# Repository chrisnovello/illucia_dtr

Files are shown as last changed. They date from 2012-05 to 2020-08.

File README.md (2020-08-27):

illucia dtr
a patchbay controller 
by [Chris Novello](http://chrisnovello.com) ([@chrisnovello](http://www.twitter.com/chrisnovello))   

It uses physical jacks and patch cables as an interface for making connections between computer programs. 

It is open source everything: hardware, software (microcontroller & computer side), and design.

For more info, visit [illucia.com](http://www.illucia.com) and read the [FAQ](http://www.illucia.com/faq/) and [user guide](http://www.illucia.com/guide/).

## Microcontroller Installation

Teensy++ 2.0
Requires installation of [Teensy extension](https://www.pjrc.com/teensy/td_download.html) for Arduino IDE. Choose correct board model from Tools menu. Click verify, press button on board, upload code to board.

* On my computer, the serial device shows up as `/dev/cu.usbmodem1421`
* Baud setting is 9600.

## Pin mappings

Pins are mapped into arrays. The index of this array is the numeric ID followed by the type of the controller.

## Firmware design 

What is a handshake?

There's a boolean, true by default that instructs the program that it "needs a handshake". Why would it not need one?

What is a Device State?

There is a class called ControlElement that has two setters. Pin number and symbolic ID. This is the base class for all other element types.

A DigitalElement inherits ControlElement with some attributes for byte value, and debouncing data. There defaults for attributes are to say debounce is false and set the byte value to something outside of the expected range. There are getters and setters for the byte data, in this case all expected byte values are boolean. The main class has a single function with no return value named updateState() with no arguments. It gets the current pin number from the parent class.

It seems like the pull up resistors for all the LED and jack connections indicate that a state change will "flip the bit". For example, if the pin read is HIGH, send a 0. From here the function allocates a 4 byte array like 

```
  byte dataToSend[MESSAGE_SIZE] = {
      DIGITAL_TYPE, lowByte(_id), valueToSend, 255
  }
```
Note last byte is FF. This is padding.

A ContinuousElement inherits ControlElement and adds a single attribute for the previous read. It has a single function named updateState() that returns an int. Why is this pattern different than the updateState() function for DigitalElement?

There is some software filtering for noise then it packs the 4 byte array like so

```
  byte bytesToSend[MESSAGE_SIZE] = {
      CONTINUOUS_TYPE, _id, highByte(reading), lowByte(reading)
  };
```

Simple!

The Jack class inherits from ControlElement but also creates instances of DigitalElement, which is strange. It looks like there is some iterative stuff going on here, which makes sense, but we really have a 4x4 matrix with each point having a streaming input or output. 

What is Debouncing? 

Debouncing appears to be a short delay window to not read a value but rather reread the value after this delay. Why this might be some kind of error correction to smooth out the electrical interference which could effect the corectness of the values coming from the controllers.

What is "first byte pertaining to the state of the grid (for now, just beaming the whole state of the grid over when something changes)"?

The serial protocol has the following structure, though there is logic within the array. Perhaps this logic could be better represented through data modeling?

[
int controllerType,
int controllerID,
byte controllerValue,
]

For example, the controllerType changes the meaning of the controllerID. If the type is a jack connection, the controllerID "beams the whole state of the grid over". I'm not sure what that means but it seems like it's larger than simply identifying the jack identifier which has changed.

Also, the controllerType changes the meaning of the controllerValue. If the type is 0, the last two bytes are the value of the controller for this sample. If the type is 1, the controllerValue is a simple boolean (1bit). If the type is 2 the controllerValue is the controllerID of the other jack connection and a boolean to signify if the connection is open or closed.

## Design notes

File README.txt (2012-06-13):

illucia dtr is a codebending instrument. 

It uses physical jacks and patch cables as an interface for making connections between computer programs. 

It is open source everything: hardware, software (microcontroller & computer side), and design.

For more information, visit:
http://www.paperkettle.com
http://www.illucia.com

http://www.twitter.com/paperkettle

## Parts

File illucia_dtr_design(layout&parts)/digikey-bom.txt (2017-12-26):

Index,Quantity,Part Number,Description,Customer Reference,Available Quantity,Backorder Quantity,Unit Price USD,Extended Price USD,
1,5,360-1801-ND,SWITCH TOGGLE SPDT 6A 125V,,5,0,3.55000,17.75,
2,5,CKN4022-ND,SWITCH PUSH SPDT 0.4VA 20V,,5,0,5.21000,26.05,
3,5,CKN1399-ND,CAP PUSHBUTTON ROUND RED,,5,0,0.86000,4.30,
4,5,360-3215-ND,NUT CONICAL INCH FOR EB/MB20 SER,,5,0,1.04000,5.20,
5,5,CLB_300_RTP-ND,LENS MT CLIPLITE 5MM RED TRANSP,,5,0,0.63000,3.15,
6,7,450-1731-ND,SWITCH KNOB STRGHT 1.02" W/SKIRT,,7,0,2.92600,20.48,
7,2,A121571-ND,CONN USB RCPT VERT A TYPE WHITE,,2,0,1.09000,2.18,
8,1,MUSBB55104-ND,CONN RUGGED USB RCPT VERT MINI B,,1,0,13.92000,13.92,
,,,,,,Subtotal,93.03
,,,,,,Shipping,unknown
,,,,,,Estimated Sales Tax,7.91
,,,,,,Total,unknown

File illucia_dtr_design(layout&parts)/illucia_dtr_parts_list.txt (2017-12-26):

illucia parts list:

========================================

Enclosure (1) [acrylic, nb]
	Hammond 1590DD
        http://www.alliedelec.com/hammond-manufacturing-1590dd/70165498/

Banana Jack (16) [nb]
	Emerson/Johnson 108-09xx-001 

Toggle Switch (4) [https://www.digikey.com/product-detail/en/nkk-switches/M2012SS1W01/360-1801-ND/1006880]
	NKK M2012SS1W01 (alt: M2012ES1W01 has bat switches)

Momentary Pushbutton (4) [https://www.digikey.com/products/en?keywords=8125SHZBE]
	C&K 8125SHZBE 

Red Button Cap (4) [https://www.digikey.com/products/en?keywords=%20801803000]
	C&K 801803000 

Conical Dress Nut (4) [https://www.digikey.com/product-detail/en/nkk-switches/AT512H/360-3215-ND/1045995]
	NKK AT512H 

LED (4) [nb]
	Diffused Red

LED Lens (4) [https://www.digikey.com/products/en?keywords=593-3000R]
	593-3000R

ESD Resistors (16) [nb] 
	100 ohms

LED Resistors [nb]
	1k

Potentiometers (6) [https://www.mammothelectronics.com/collections/alpha-pcb-mount/products/alpha-16mm-single-gang-long-pin-right-angle-pc-mount-logarithmic-a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]
	RV16AF-42-15R1-A10k Linear Alpha Single-Gang 16mm Right Angle PC Mount Long-Pin

Knobs (6) [https://www.digikey.com/products/en?keywords=506-PKD70B1%2F4]
	506-PKD70B1/4

USB A Receptacle (1) [https://www.digikey.com/products/en?keywords=1734366-2]
	1734366-2
 
Amphenol Rugged Mini USB Receptacle (1) [https://www.digikey.com/products/en?keywords=MUSB-B551-04]
	MUSB-B551-04

Screws (2) [nb]
	M2.5 (I think… whatever fits amphenol's threads)

Teensy++ w/header pins (1) [https://www.pjrc.com/store/teensypp.html]
	
Female Headers20 pin .1" spacing female headers (2) [nb]

== Distributors ==

NKK Switches
http://www.nkkswitches.com/

C&K Switches
http://www.ckswitches.com/

Digikey Electronics
https://www.digikey.com

PJRC
https://www.pjrc.com//

== Digikey BOM ==

http://www.digikey.com/short/3dztqt

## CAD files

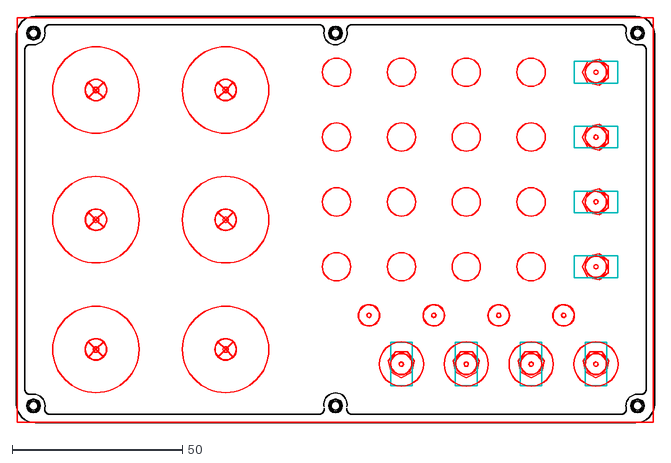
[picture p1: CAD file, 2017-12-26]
illucia_dtr_design(layout&parts)/vector/holes_mm.dxf
187.5 x 119.4

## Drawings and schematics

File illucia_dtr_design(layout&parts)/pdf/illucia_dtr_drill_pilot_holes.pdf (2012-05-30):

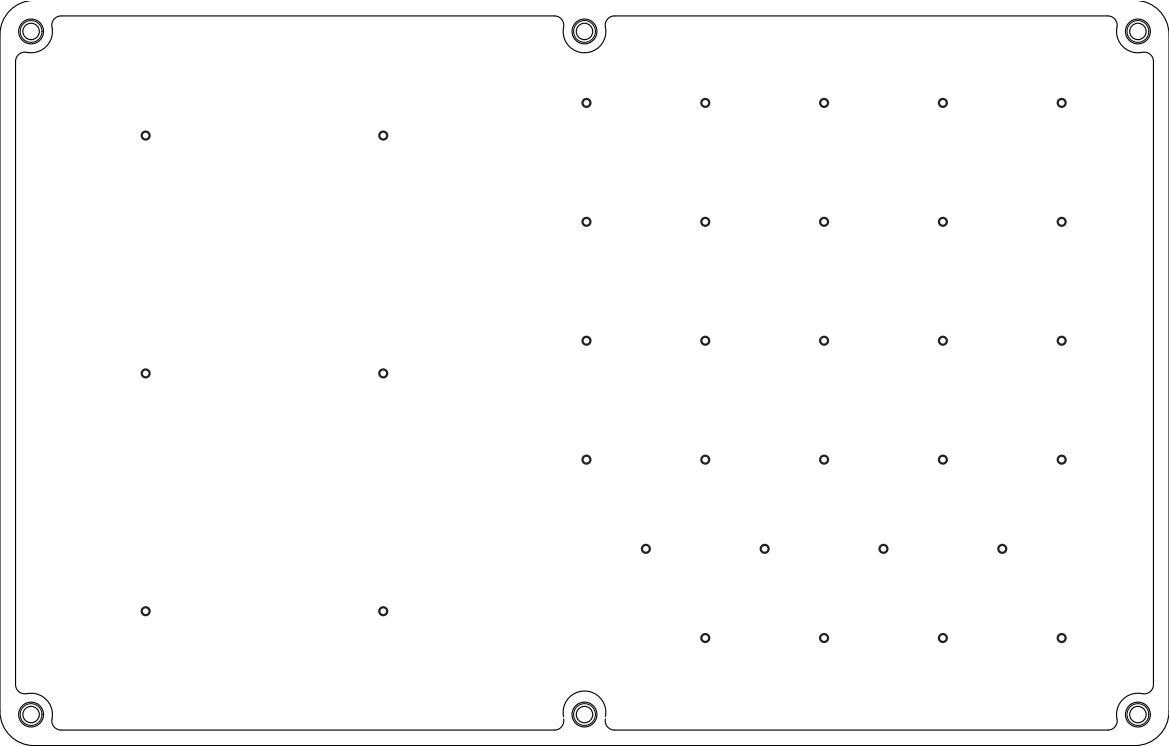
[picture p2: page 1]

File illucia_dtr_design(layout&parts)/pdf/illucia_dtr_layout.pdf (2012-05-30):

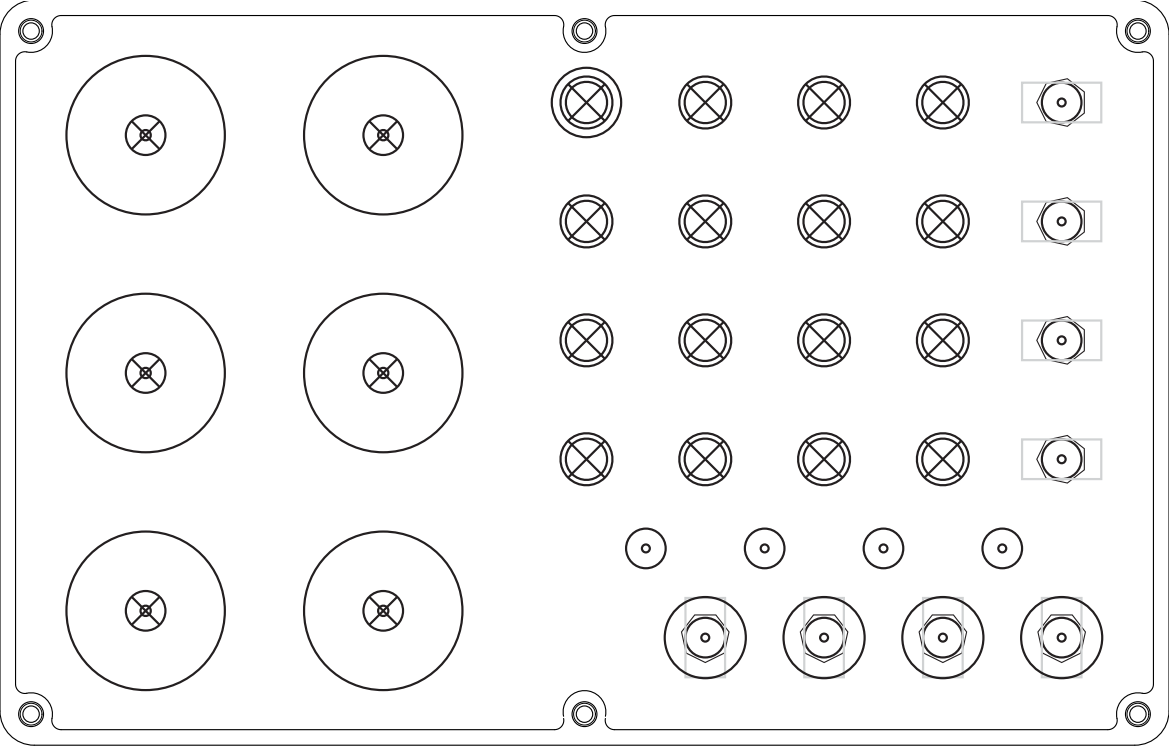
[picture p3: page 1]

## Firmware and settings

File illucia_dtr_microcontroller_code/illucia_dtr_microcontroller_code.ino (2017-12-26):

/*
 Todo:
 -After first correspondence handshake, broadcast information about device
 Computer will use this to dynamically create a model of the device
 */

/*
 illucia dtr
 "deterritorializer"
 microcontroller code version 0.9
 arduino style code (with Teensy++ as the intended target at the moment)
 
 When there is a change in state, send a message to the computer specifiying the change. 
 The message is a 4 byte array with the makeup:
 
 //first byte: char representaiton of type of control element that this message pertains to
 0 = continuous (potentiometer, sensor, etc)
 1 = digital (button, switch, etc)
 2 = jack event (some jack connection or disconnection)
 3 = arbitrary data (currently unused)
 
 //second byte
 if continous or digital: ID number of control element (ie: which pot changed, or which button changed)
 if jack events: first byte pertaining to the state of the grid (for now, just beaming the whole state of the grid over when something changes)
 if arbitrary data: first byte of whatever data is being sent
 
 //remaining bytes:
 if continuous: send 2 bytes (the 10bit value from the analogRead) 
 if digital: send 1 byte (only 1 bit used). send 1 for pressed, 0 for released 
 if jack event: another jack is involved, so send its ID in the next byte, and another byte pertaining to the state (0 for a disconnection, 1 for a connection)
 */

//Constants:
byte const CONTINUOUS_TYPE = 0;
byte const DIGITAL_TYPE = 1;
byte const JACK_TYPE = 2;

int const MESSAGE_SIZE = 4; //4 bytes transmitted every serial message

int const NUMBER_OF_DIGITAL_ELEMENTS = 8; // how many buttons & switches?
int const NUMBER_OF_CONTINUOUS_ELEMENTS = 6; // how many continuous controls?
int const NUMBER_OF_JACKS = 16; //how many jacks are on this device?

//debouncing&smoothing
int const DEBOUNCE_DELAY = 20;//how many MS should you wait for a debounced value?
int const ANALOG_CHANGE_THRESHOLD = 6; //used for software smoothing of analogRead jitter

//For incoming data to microcontroller:
byte const RESET_TYPE = 0; //used to tell the device to go back to waiting for a handshake
byte const LED_TYPE = 1; //used to specify an LED's brightness
int const NUMBER_OF_LEDS = 4; //how many LEDs are on this device?


//Pin Setup
//these are lists of the microcontroller pins used. the order that they're listed will determine the control element's ID (as in, what number button or switch or potentiometer etc)
int digitalElementPins[] = { //pins hooked up to "digital" elements like buttons / switches. 
    18, 19, 20, 21, 22, 23, 44 ,45
}; 
int continuousElementPins[] = { //analog I/O (aka pots.... FRESH POTS!!!!)
    0, 1, 2, 3, 4, 5
};
int jackPins[] = {
    0,1,2,3,4,5,7,8,9,10,11,12,13,14,15,16
    //  17, 16, 15, 13, 12, 11, 10, 9, 32, 33, 34, 35, 8, 7, 5, 4
};
int ledPins[] = {
    24, 25, 26, 27
};



boolean needsHandshake = true; //used to determine if communication has been initiated with the device or not

//Base class for keeping track of the device's state
class ControlElement {
public:
    
    int _pinNumber; //the microcontroller pin associated with this element
    int _id; //the number of this element (aka, is it jack1, jack2, knob1, knob2, etc)
    
    void setPinNumber(int pinNumber) {
        _pinNumber = pinNumber; 
    }
    
    void setId(int id) {
        _id = id; 
    }
    
};


//Used to keep state of switches, buttons, jack connections.. anything that is on/off, needs debouncing, and is checked with a digital pin on the microcontroller
class DigitalElement : public ControlElement {
public:
    
    byte _value;
    
    boolean _debouncing;
    unsigned long _timeDebounceStarted;
    
    DigitalElement() {
        _debouncing = false;
        
        //initializing _value outside of the range of expected values (0 or 1) 
        //such that it will register the first read as a change in value, and thus broadcast the initial state of the device 
        _value = 3; 
    }
    
    void setValue(byte value) {
        _value = value; 
    }
    byte getValue() {
        return _value; 
    }
    
    void setTimeDebounceStarted(unsigned long timeDebounceStarted) {
        _timeDebounceStarted = timeDebounceStarted;
    }
    unsigned long getTimeDebounceStarted() {
        return _timeDebounceStarted;
    }
    
    void setDebouncing (boolean debouncing) {
        _debouncing = debouncing;
    }
    boolean isDebouncing() {
        return _debouncing;
    }
    
    void updateState() {
        int currentReading = digitalRead(_pinNumber);
        
        if (_value != currentReading) { //there is a state change, or this is the very first time checking state
            
            if (_debouncing ) {
                
                if (_timeDebounceStarted + DEBOUNCE_DELAY <= millis()) { //if the debounce delay has passed
                    
                    _debouncing = false; //done debouncing
                    _value = currentReading; //set the current value
                    
                    byte valueToSend; //send opposite of the read, given pull up resisitors
                    if (_value == HIGH) {
                        valueToSend = 0;
                    } 
                    else {
                        valueToSend = 1;
                    }
                    
                    //pack a byte array with data about the state change
                    byte dataToSend[MESSAGE_SIZE] = {
                        DIGITAL_TYPE, lowByte(_id), valueToSend, 255
                    }; //dummy byte at the end - easier to send everything as packets of the same size.. might change this down the road if there is some need to send arbitrary data.
                    Serial.write(dataToSend, MESSAGE_SIZE); //send it over serial.
                    
                }
            }
            else { //this is the first time we've read a state change, and thus should prepare a debounce, re-read after a delay
                _debouncing = true;
                _timeDebounceStarted = millis();
            }
        }
    }
};


//Used to keep state of knobs, sensors.. anything where a variable voltage range is read from an analog pin on the microcontroller
class ContinuousElement : public ControlElement {
public:
    
    int _previousRead; //used to keep track of readings in order to average / minimize noise on the analog readings
    
    int updateState() {
        
        int reading = analogRead(_pinNumber);
        
        //factor out noise
        int difference = _previousRead - reading;
        
        if (abs(difference) > ANALOG_CHANGE_THRESHOLD) { //simple software way of factoring out fluctations in reading due to noise/power  
            
            //check for edge cases, so pot doesn't miss full CW or CCW positions given software filtering
            if (reading <= ANALOG_CHANGE_THRESHOLD) {
             reading = 0; 
            } else if (reading >= 1023 - ANALOG_CHANGE_THRESHOLD) {
              reading = 1023;
            }
            
            
            //send update!
            byte bytesToSend[MESSAGE_SIZE] = {
                CONTINUOUS_TYPE, _id, highByte(reading), lowByte(reading)
            };
            Serial.write(bytesToSend, MESSAGE_SIZE);
            
            //update internal state  
            _previousRead = reading;
        }
    }
};


//Used to keep state of the patchbay's jacks. Wrapper around a digital element array 
class Jack : public ControlElement {
public:   
    
    //Each jack keeps track of which other jacks it is connected to.
    //uses "DigitalElements" because a jack connection behaves like a switch
    DigitalElement _connectionState[NUMBER_OF_JACKS]; //could be NUMBER_OF_JACKS-1 but might complicate index versus jack#.. so will leave it for now..
    
    Jack() {
        //When this jack is created, setup all of its possible connections 
        for (int i = 0; i < NUMBER_OF_JACKS; i++) {
            
            _connectionState[i].setPinNumber(jackPins[i]);
            _connectionState[i].setId(i);
            // _connectionState[i].setValue(HIGH); //initialize to HIGH (aka no connection, given pull up resistors)
        }
    }
    
    void updateState() {
        //turn this jack low, then check all the others to see what has changed. 
        
        //flip the jack you're checking to an output
        pinMode(_pinNumber, OUTPUT);
        digitalWrite(_pinNumber, LOW); // should bring all the other pins that it is connected to (inputs with pullups on) to LOW/Ground
        
        for (int i = 0; i < NUMBER_OF_JACKS; i++) { //look for changes
            
            int currentReading = digitalRead(_connectionState[i]._pinNumber); //find out if there is a connection with this jack or not. 
            
            if (i != _id) { //this just means "don't check this pin for connections with itself"
                
                if (_connectionState[i].getValue() != currentReading) { //"is this reading different from what is already recorded as the state?" or, is it the first re
                    
                    if (_connectionState[i].isDebouncing()) {//"and did we already record that this state change occured, but we're still debouncing?"
                        
                        if (_connectionState[i].getTimeDebounceStarted() + DEBOUNCE_DELAY <= millis()) { //"and if so, has the debounce delay passed such that we can now send the update?"
                            
                            _connectionState[i].setDebouncing(false); //done debouncing, so reset the flag
                            _connectionState[i].setValue(currentReading); //set the current value
                            
                            byte value; //send opposite of the read, given pull up resisitors
                            if (_connectionState[i].getValue() == HIGH) {
                                value = 0;
                            } 
                            else {
                                value = 1;
                            }
                            
                            byte dataToSend[MESSAGE_SIZE] = {
                                JACK_TYPE, lowByte(_id), lowByte(i), value
                            }; //make a byte array to send over serial. indicate the type of message, the two jacks, and their connection status
                            Serial.write(dataToSend, MESSAGE_SIZE); //send it over serial.
                        }
                    }
                    else { //this is the first time we've read a state change, and thus should prepare a debounce, re-read after a delay
                        _connectionState[i].setDebouncing(true);
                        _connectionState[i].setTimeDebounceStarted(millis());
                    }
                }
            }
        }
        
        pinMode(_pinNumber, INPUT);
        digitalWrite(_pinNumber, HIGH); // pull-up gets turned on again so that other jacks can check their connection to this one.
    }
};

//Arrays of elements - state needs to be maintained so that the device can send updates only upon changes (also, state is needed for debouncing, and analog signal smoothing)
DigitalElement digitalState[NUMBER_OF_DIGITAL_ELEMENTS];
ContinuousElement continuousState[NUMBER_OF_CONTINUOUS_ELEMENTS * 2]; //need 2 byts for every continous controller
Jack jacks[NUMBER_OF_JACKS]; //contains every jack. every jack then knows what other jacks it is patched into

void updateDigitalElements() {
    
    for (int i = 0; i < NUMBER_OF_DIGITAL_ELEMENTS; i++) {
        digitalState[i].updateState();
    }
}

void updateContinuousElements() {
    for (int i = 0; i < NUMBER_OF_CONTINUOUS_ELEMENTS; i++) {
        continuousState[i].updateState();
    }
}


void updateJacks() {
    for (int i = 0; i < NUMBER_OF_JACKS; i++) {
        jacks[i].updateState();
    }
}

void setup() {
    
    Serial.begin(9600);
    
    //setup pins, engage pull ups
    for (int i = 0; i < NUMBER_OF_DIGITAL_ELEMENTS; i++) {
        
        pinMode(digitalElementPins[i], INPUT);
        digitalWrite(digitalElementPins[i], HIGH);
        
        digitalState[i].setId(i); //keep track of the element number
        digitalState[i].setPinNumber(digitalElementPins[i]);
    }
    
    for (int i = 0; i < NUMBER_OF_CONTINUOUS_ELEMENTS; i++) {
        continuousState[i].setPinNumber(continuousElementPins[i]);
        continuousState[i].setId(i);
    }
    
    for (int i = 0; i < NUMBER_OF_JACKS; i++) {
        pinMode(jackPins[i], INPUT);
        digitalWrite(jackPins[i], HIGH);
        
        jacks[i].setId(i);
        jacks[i].setPinNumber(jackPins[i]);
    }
    
    for (int i = 0; i < NUMBER_OF_LEDS; i++) {
        pinMode(ledPins[i], OUTPUT);
    }
    
    for (int j = 0; j < 2; j++) {
        for (int i = 0; i < NUMBER_OF_LEDS; i++) {
            analogWrite(ledPins[i], random(20));
            delay(45); //init sequence
            analogWrite(ledPins[i], 0);
        }
        
        for (int i = NUMBER_OF_LEDS - 1; i >= 0; i--) {
            analogWrite(ledPins[i], random(255));
            delay(90); //init sequence
            analogWrite(ledPins[i], 0);
        }
    }
    
}


void loop() {

    digitalWrite(6, HIGH);
    if (needsHandshake) {
        
        //do serial handshake. 
        byte initMessage[MESSAGE_SIZE] = {
            'd', 'e', 't', 'r'
        };
        while (Serial.available () <= 0) {
            Serial.write(initMessage, MESSAGE_SIZE);
            delay(1000);
        }
        Serial.flush();
        
        needsHandshake = false;
        
        for (int j = 0; j < 2; j++) {
            for (int i = 0; i < NUMBER_OF_LEDS; i++) {
                analogWrite(ledPins[i], 255);
                delay(45); //init sequence
                analogWrite(ledPins[i], 0);
            }
        }
        
    } else {
        
        //update elements
        updateDigitalElements();
        updateContinuousElements();
        updateJacks();
        
        
        delay(1);
        //
        while (Serial.available () > 0) {
            
            //illucia also recieves serial messages            
            
            // if (Serial.available() % MESSAGE_SIZE == 0) {
            if (Serial.available() > 0) {
                
                byte type = Serial.read();
                
                if (type == LED_TYPE) {  
                    
                    while(Serial.available() < 2) {
                        //make sure you have received the two bytes specifying the LED value
                    }
                    
                    byte id = Serial.read();
                    byte value = Serial.read();
                    
                    analogWrite(ledPins[id], value);
                    
                }
                else if (type == RESET_TYPE) {
                    needsHandshake = true;
                } 
            }
            else {
                Serial.flush();
            }
        }
        
    }
}



//Note to self: 1st prototype had this pinout:

/*
int digitalElementPins[] = {
  18, 19, 20, 21, 28, 29, 30, 31
}; //pins hooked up to "digital" elements like buttons / switches. 
int continuousElementPins[] = {
  45, 44, 43, 42, 40, 39
};
int jackPins[] = {
  17, 16, 15, 13, 12, 11, 10, 9, 32, 33, 34, 35, 8, 7, 5, 4
};
int ledPins[] = {
  24, 25, 26, 27
};
*/

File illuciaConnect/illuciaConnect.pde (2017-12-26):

//Change these values if you'd like to change illuciaConnect's ports!
final int OSC_INCOMING_PORT = 12000;
final int OSC_OUTGOING_PORT = 12001;

//Todo: 

//automatically get device info at boot.
//make model of device OO, support multiple devices plugged in at once...
//make it so one can connect illucia devices after launch
//make it so user selects device from serial list..? and has connect/disconnect buttons in the utility?
//create a keepalive signal on the illucia unit, then automatically close the serial port if a timepassedSinceLastPacket > keepalive

import processing.serial.*;
import oscP5.*;
import netP5.*;

Serial serialConnection;
OscP5 oscP5;
NetAddress myRemoteLocation;

//Data ranges//////////////////////////////////////////////// 
//The microcontrollers I'm using have 10bit A->D converters...
final float microcontrollerLow = 0;
final float microcontrollerHigh = 1023;
//...which get mapped to this standardized range for the sake of seamless/universal communication with other software
final float OSCLow = 0.0;
final float OSCHigh = 1.0;

////Serial protocol////////////////////////////////////////////////
//incoming
//The hardware device will send a set of bytes upon state change (aka, a button pressed, jacks patched together, knob turned, etc) 
final int MESSAGE_SIZE = 4; //this is number of bytes in each serial message sent by the hardware 
//The first byte will denote the type of change being communicated. 
final byte CONTINUOUS_TYPE = 0; //Knobs
final byte DIGITAL_TYPE = 1; //Buttons & Switches
final byte JACK_TYPE = 2; //Jack connections & disconnections 

//outgoing
final byte RESET_TYPE = 0;
final byte LED_TYPE = 1;
///
boolean serialConnected = false; // has illucaConnect initialized a serial connection 
boolean handShakeCompleted = false; //has the device successfully completed a handshake with this program? 

//TODO: automatically get this from device at boot.
//Device details... 
String deviceName = "dtr";
final int NUMBER_OF_DIGITAL_ELEMENTS = 8;
final int NUMBER_OF_CONTINUOUS_ELEMENTS = 6;
final int NUMBER_OF_JACKS = 16;
final int NUMBER_OF_LEDS = 4;
//int versionNumber;

//Create a place to store illucia device state
float[] digitalElements;
float[] continuousElements;
Jack[] jacks; 

//Images to show connected/disconnected status
PImage[] connectionStatusImages;

void setup() {
  size(300, 300);  
  background(255);

  connectionStatusImages = new PImage[2];

  //try to load images
  //connectionStatusImages[0] = loadImage("illuciaNotConnected.png");
  //connectionStatusImages[1] = loadImage("illuciaConnected.png");
  //call the helper that renders text and images
  setConnectionStatus(false);

  noLoop(); //disable the draw() loop, as this program is event driven for now
  //low frame rates = less CPU usage. 
  frameRate(1); //useless.. at the moment, drawing is disabled in this sketch. Might get readded later though

  //initialize OSC 
  oscP5 = new OscP5(this, OSC_INCOMING_PORT);
  myRemoteLocation = new NetAddress("127.0.0.1", OSC_OUTGOING_PORT);

  //initialize serial
  connectOverSerial();

  //Setup the model of the device
  //buttons&switches
  digitalElements = new float[NUMBER_OF_DIGITAL_ELEMENTS];
  //knobs
  continuousElements = new float[NUMBER_OF_CONTINUOUS_ELEMENTS];
  //jacks...
  jacks = new Jack[NUMBER_OF_JACKS];
  for (int i = 0; i < jacks.length; i++) {
    jacks[i] = new Jack(i);
  }

  prepareExitHandler(); //sets up an event handled that is called upon program's closing. Tells device to reset to a new state and await a new handshake
}


void draw() {
}

//This gets called by the serial library when something on the device changes
void serialEvent(Serial port) {

  byte[] incoming = new byte[MESSAGE_SIZE];

  if (!handShakeCompleted && serialConnection.available () >= incoming.length && serialConnection.available() % incoming.length == 0) { //has this device connected before? if not, check for a initial handshake 

    println("Starting handshake..");

    /* if this is the first serialEvent, 
     make sure the connection has enough time to get setup before reading
     */
    delay(2000); 

    serialConnection.readBytes(incoming);

    if (incoming[0] == 'd') {

      serialConnection.write('P');
      println("Handshake Complete");
      println("Bytes available after handshake and clear: "+serialConnection.available());

      //after handshake, update the display
      setConnectionStatus(true);
      handShakeCompleted = true;

      serialConnection.clear();
    }
  }

  else { //Initial handshake has already been established

    //println("Available: " + serialConnection.available());

    while (serialConnection.available () >= incoming.length && serialConnection.available() % incoming.length == 0) {

      serialConnection.readBytes(incoming);
      
      //println("reading");
      // for (int i = 0; i < incoming.length; i++) {
      // println(i+"'s value: "+incoming[i]);
      // } 
     
      OscMessage messageToSend;

      //println("Ready to send OSC messages");

      switch(incoming[0]) { //Switch the serial bytes based on the byte that specifies message type
      case CONTINUOUS_TYPE:

        //what number element(knob) is this?
        int continuousElementIndex = incoming[1];

        float contValue = int(incoming[2] << 8) + int(incoming[3]);
        contValue = map(contValue, microcontrollerLow, microcontrollerHigh, OSCLow, OSCHigh);

        //update model of device
        continuousElements[continuousElementIndex] = contValue;

        //Now, broadcast the value change over OSC

        //control elements are indexed at 0 on the hardware, but 1 in software, so add 1 when sending this value out
        String msgC = "/"+deviceName+"/Continuous/"+(continuousElementIndex + 1);
        messageToSend = new OscMessage(msgC);  
        messageToSend.add(contValue);
        //println(msgC + " " + contValue);
        oscP5.send(messageToSend, myRemoteLocation);

        //println("Pot ID: "+ incoming[1] + " value: "  +contValue);
        break;


      case DIGITAL_TYPE:

        //what number element(button or switch) is this?
        int digitalElementIndex = incoming[1];

        float value = 0.0;

        if (incoming[2] == 1) { //switch or button is activated
          value = 1.0;
        } 
        else if (incoming[2] == 0) { //switch or button is off
          value = 0.0;
        }

        //update model of device
        digitalElements[digitalElementIndex] = value;

        //now, broadcast the value change over OSC

        //control element numbers are indexed at 0 on the hardware, but 1 in software, so add 1
        String msgD = "/"+deviceName+"/Digital/"+(digitalElementIndex+1);
        messageToSend = new OscMessage(msgD);  
        messageToSend.add(value);
        //println(msgD + " " + value);
        oscP5.send(messageToSend, myRemoteLocation);

        //println("Button ID: "+ incoming[1] + " value: "  +incoming[2]);    
        break;
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

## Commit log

2012-06-01 adding pcbs
    [illucia_dtr_teensy_v1.0.brd, illucia_dtr_teensy_v1.0.sch, usb_breakout_1.0.brd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]
2012-06-13 updated microcontroller code - tweaked pot smoothing and added edge cases (next big hardware release should use caps for circuit level filtering/smoothing)
2014-02-17 Tightened serial communication / now compatible with Processing 2.1.1's new library
    [illuciaConnect.pde]
2017-05-30 Othermill software needs "XML format"
    [usb_breakout_1.0-text.brd]
2017-06-03 light up the onboard LED when the firmware is loaded
2017-12-26 include DXF of panel for Autodesk software
    [holes_mm.dxf]
